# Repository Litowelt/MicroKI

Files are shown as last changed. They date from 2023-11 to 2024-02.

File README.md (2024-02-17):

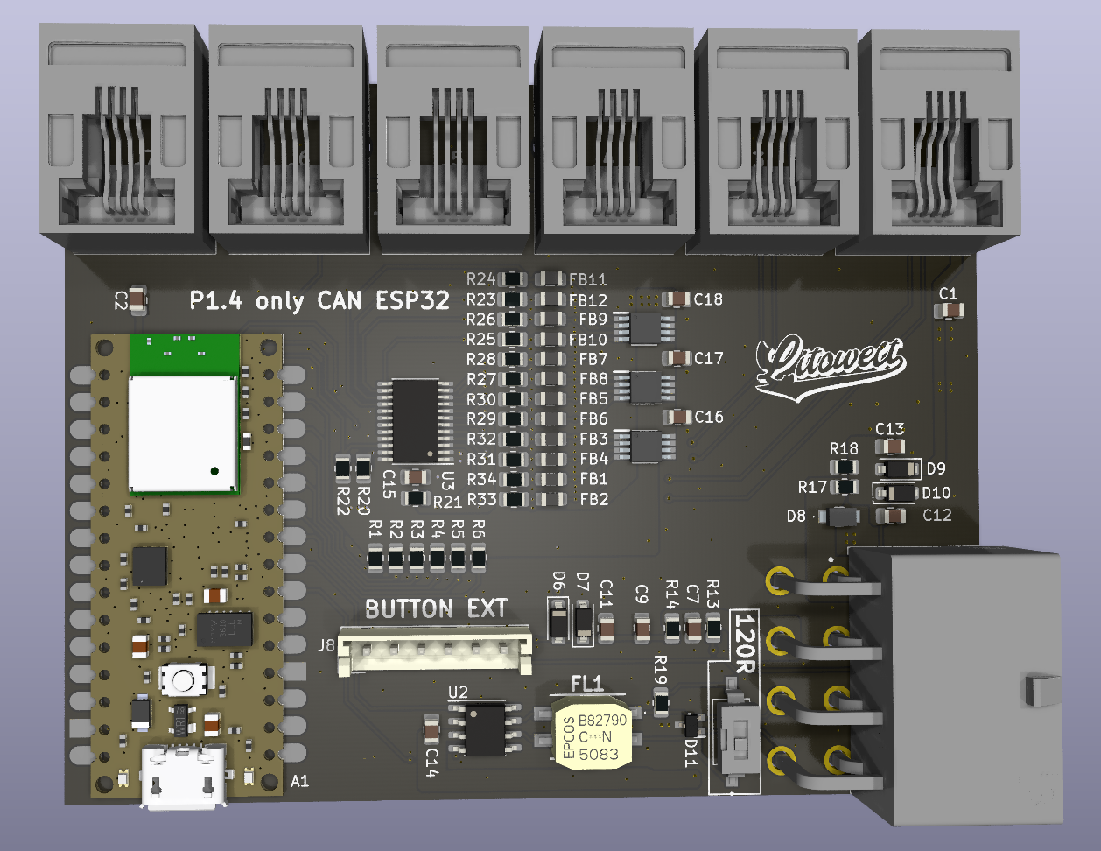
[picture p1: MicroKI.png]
HierSollteEigentlichEinFotoSein...


# MicroKI

Das "MicroKI" ist ein Projekt, das sich mit digitalen Zusatzanzeigen befasst. Das MicroKI ermöglicht den Anschluss von bis zu 6 Zusatzanzeigen (0.96" OLED LCDs) an ein System. Die Daten für diese Anzeigen können entweder über den CAN-Bus (1x) oder über externe Sensor-Eingänge bezogen werden. Es stehen verschiedene externe Sensor-Eingänge zur Verfügung, darunter Batterie Spannung und Öldruck. Jede der 6 Anzeigen kann separat angesteuert werden und die Daten können über Tasten auf der Platine oder externe Tasten umgeschaltet werden.

# Anschluss Übersicht
Digitale Zusatzanzeigen (0.96" OLED LCDs):

- Bis zu 6 dieser Displays können an das MicroKI angeschlossen werden.

Datenquelle:

- Die Daten können über den CAN-Bus (1x) oder über externe Sensor-Eingänge bezogen werden.
  
Externe Sensor-Eingänge:

- 1x Batterie Spannung
- 1x Öldruck Sensor (VDO)
  
Steuerung und Umschaltung:

- Alle 6 Anzeigen können separat angesteuert werden.
- Die Umschaltung zwischen den Anzeigen und die Steuerung erfolgen entweder über die Buttons auf der Platine oder über externe Buttons.

# Unterstütze Fahrzeuge und Nachrichten

- VW T5.1
  - Öl Temperatur (wenn der Sensor verbaut ist) - ✓
  - Kühlwasser Temperatur - ✓
  - Ladeluft Temperatur - ✓
  - Außentemperatur (wenn der Sensor verbaut ist) - ✓
  - Ladedruck - ✓
 
- Universal (Analoge Eingänge)
  - Öl Temperatur - X
  - Kühlwasser Temperatur - X
  - Außentemperatur - X
  - Öldruck - X
  - Ladedruck - X
 
# ToDo
- Code fertig schreiben. - in Arbeit
- Prototypen V2 bauen (Bauteile und Platinen sind bestellt).
- CAN Nachrichten für T5.2 heraus finden. - Müssen nur noch final getestet werden
- CAN Support für Haltech ECU hinzufügen - in Arbeit
- CAN Support für Ecumaster EMU ECU hinzufügen - in Arbeit
- CAN Support für Maxx ECU hinzufügen - in Arbeit

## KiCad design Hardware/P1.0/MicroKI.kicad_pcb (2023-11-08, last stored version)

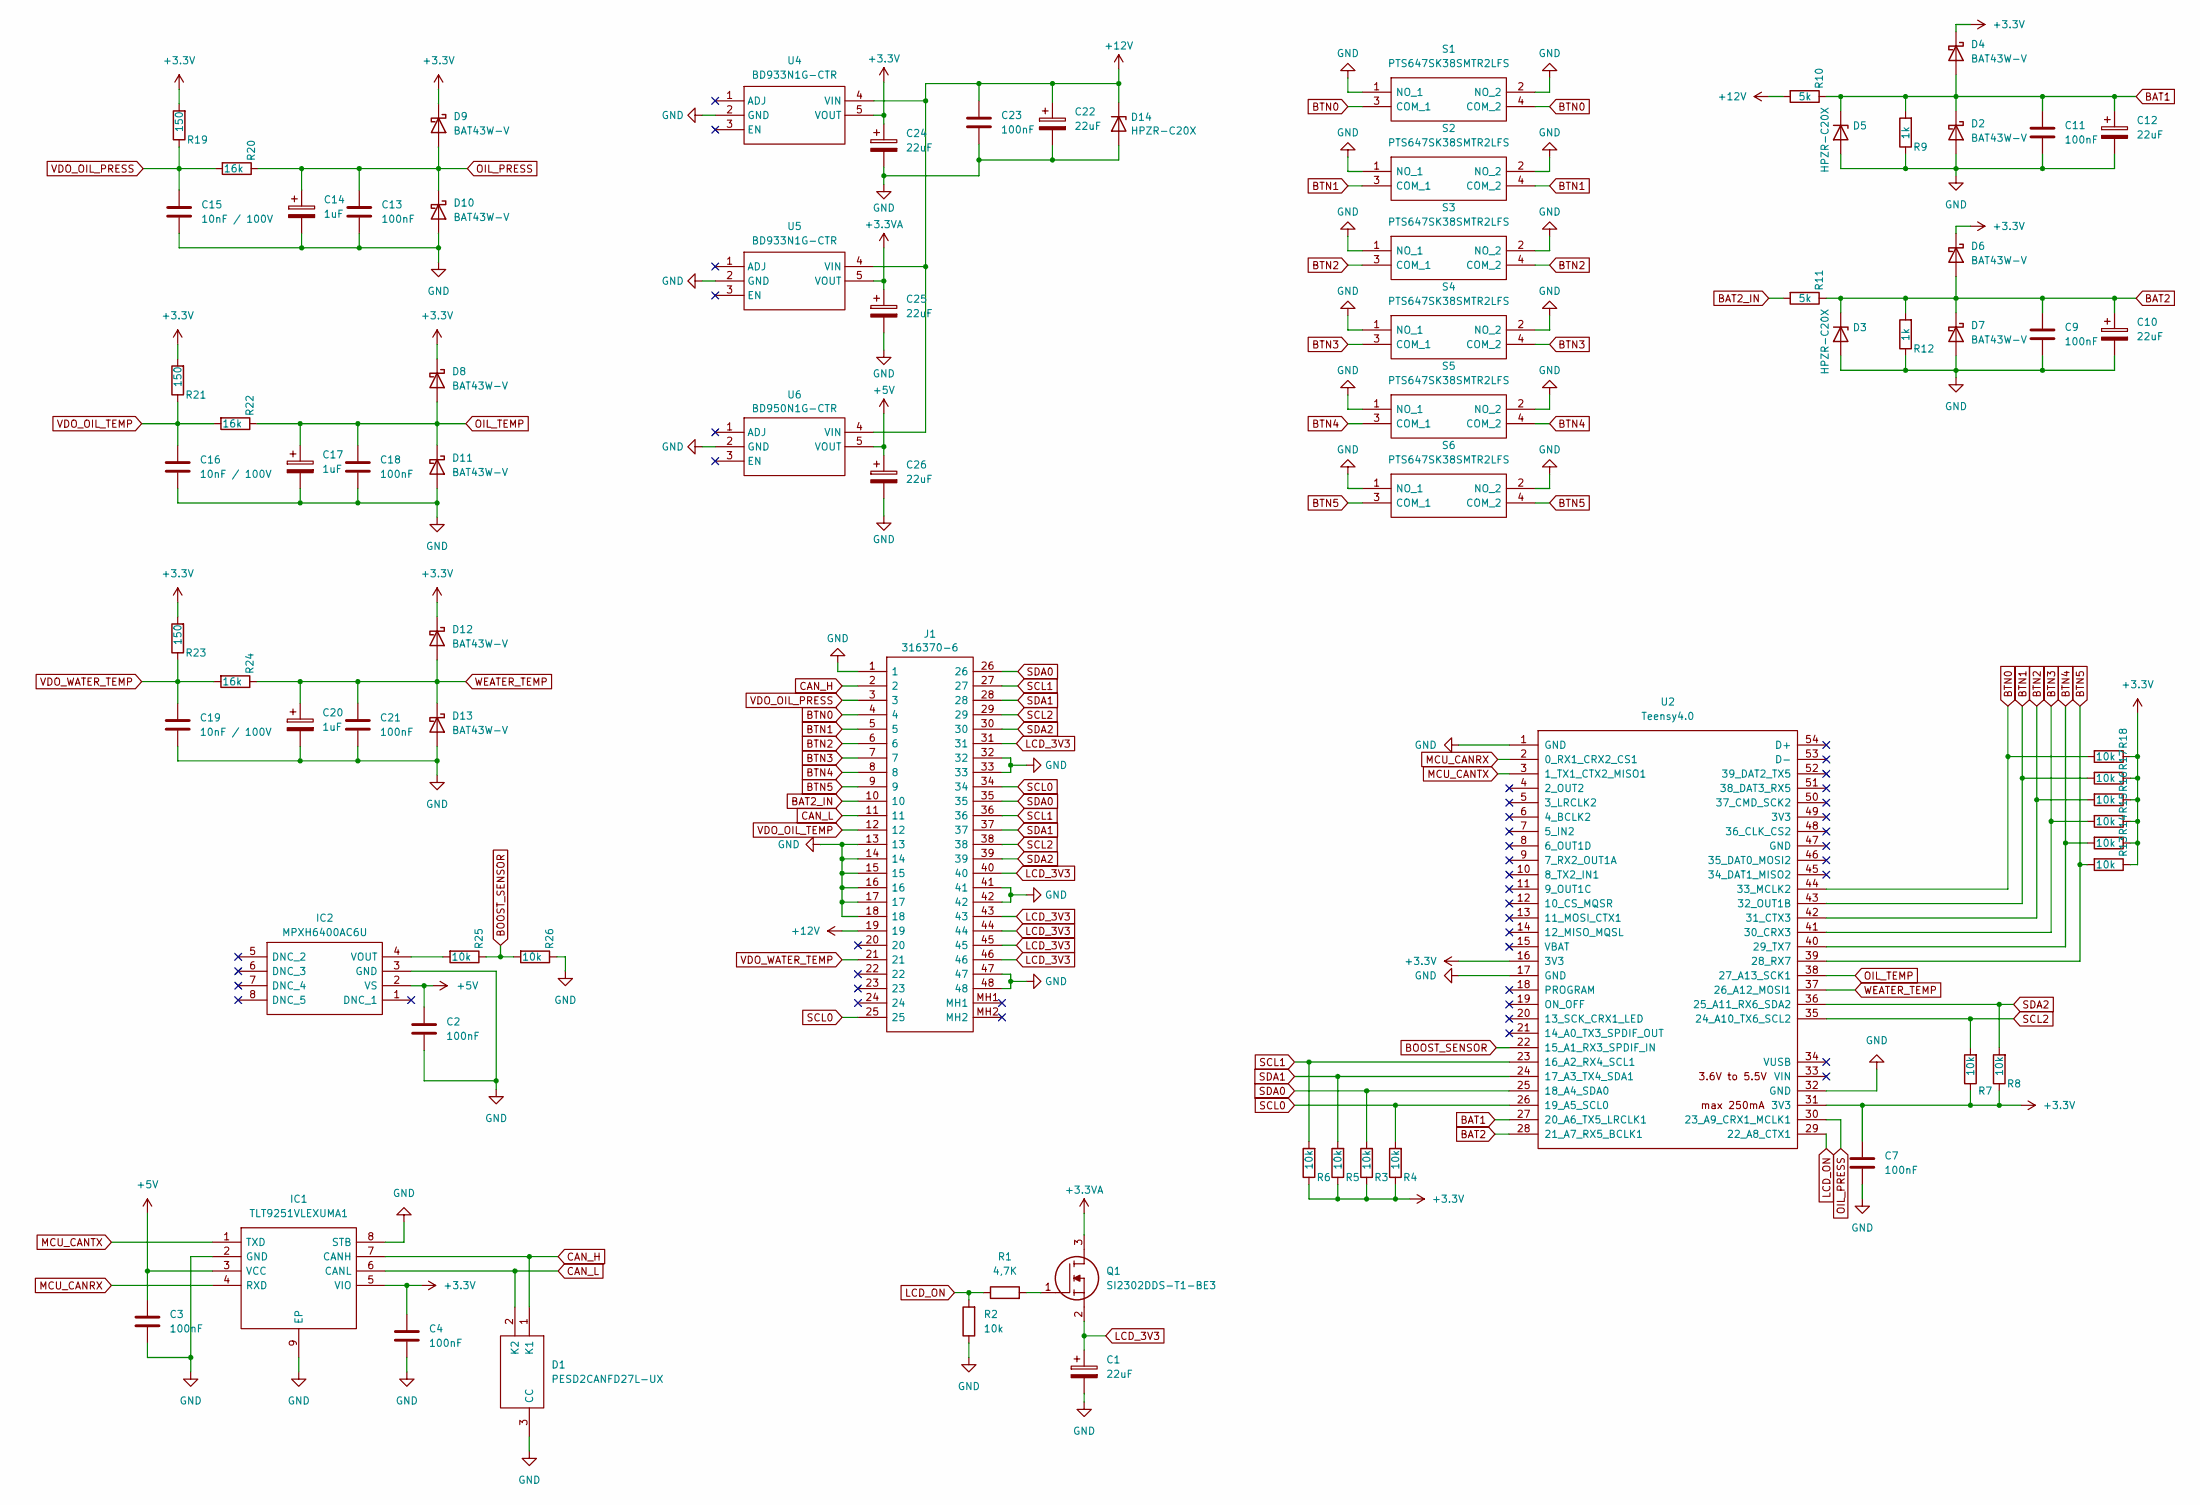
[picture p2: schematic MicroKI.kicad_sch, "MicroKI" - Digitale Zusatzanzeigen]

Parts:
C1, C10, C12, C22, C24, C25, C26: 22uF; CP_Elec_5x5.4; Manufacturer_Part_Number 865080442004; Mouser Part Number 710-865080442004
C2, C3, C4, C7, C9, C11, C13, C18, C21, C23: 100nF; C_0805_2012Metric_Pad1.18x1.45mm_HandSolder; Manufacturer_Part_Number C0805C104M5RAC7025; Mouser Part Number 80-C0805C104M5RACTM
C14, C17, C20: 1uF; CP_Elec_4x5.7; Manufacturer_Part_Number 865060640001; Mouser Part Number 710-865060640001
C15, C16, C19: 10nF / 100V; C_0603_1608Metric_Pad1.08x0.95mm_HandSolder; Manufacturer_Part_Number GCM188R72A103KA37J; Mouser Part Number 81-GCM188R72A103KA7J
D1: PESD2CANFD27L-UX; SOT65P210X110-3N; Mouser Part Number 771-PESD2CANFD27L-UX
D2, D4, D6, D7, D8, D9, D10, D11, D12, D13: BAT43W-V; D_SOD-123; Manufacturer_Part_Number BAT43W-G3-08; Mouser Part Number 78-BAT43W-G3-08
D3, D5, D14: HPZR-C20X; HPZRC20X; Manufacturer_Part_Number HPZR-C20X; Mouser Part Number 771-HPZR-C20X
IC1: TLT9251VLEXUMA1; SON65P300X300X110-9N; Manufacturer_Part_Number TLT9251VLEXUMA1; Mouser Part Number 726-TLT9251VLEXUMA1
IC2: MPXH6400AC6U; MPXH6115AC6U; Mouser Part Number 841-MPXH6400AC6U
J1: 316370-6; 3163706; Mouser Part Number 571-316370-6
Q1: SI2302DDS-T1-BE3; SOT95P237X112-3N; Mouser Part Number 78-SI2302DDS-T1-BE3
R1: 4,7K; R_0805_2012Metric_Pad1.20x1.40mm_HandSolder; Manufacturer_Part_Number RK73B2ATTD472J; Mouser Part Number 660-RK73B2ATTD472J
R2, R3, R4, R5, R6, R7, R8, R13, R14, R15, R16, R17, R18, R25, R26: 10k; R_0805_2012Metric_Pad1.20x1.40mm_HandSolder; Manufacturer_Part_Number RC0805FR-1010KL; Mouser Part Number 603-RC0805FR-1010KL
R9, R12: 1k; R_0805_2012Metric_Pad1.20x1.40mm_HandSolder; Manufacturer_Part_Number ERJ-P06D1001V; Mouser Part Number 667-ERJ-P06D1001V
R10, R11: 5k; R_0805_2012Metric_Pad1.20x1.40mm_HandSolder; Manufacturer_Part_Number CRCW08055K00FKTA; Mouser Part Number 71-CRCW0805-5K
R19, R21, R23: 150; R_0805_2012Metric_Pad1.20x1.40mm_HandSolder; Manufacturer_Part_Number ERJ-P06D1500V; Mouser Part Number 667-ERJ-P06D1500V
R20, R22, R24: 16k; R_0805_2012Metric_Pad1.20x1.40mm_HandSolder; Manufacturer_Part_Number RC0805FR-0716KL; Mouser Part Number 603-RC0805FR-0716KL
S1, S2, S3, S4, S5, S6: PTS647SK38SMTR2LFS; Mouser Part Number 611-PTS647SK38SMTR2L
U2: Teensy4.0; Teensy40_SMT
U4, U5: BD933N1G-CTR; BD9xxN1WG-CTR; Manufacturer_Part_Number BD933N1G-CTR; Mouser Part Number 755-BD933N1G-CTR
U6: BD950N1G-CTR; BD9xxN1WG-CTR; Manufacturer_Part_Number BD950N1G-CTR; Mouser Part Number 755-BD950N1G-CTR

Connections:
+3.3V: C4.1, C7.1, C24.1, D4.1 (K), D6.1 (K), D8.1 (K), D9.1 (K), D12.1 (K), IC1.5 (VIO), R3.1, R4.1, R5.1, R6.1, R7.1, R8.1, R13.1, R14.1, R15.1, R16.1, R17.1, R18.1, R19.2, R21.2, R23.2, U2.16 (3V3), U2.31 (3V3), U4.5 (VOUT)
+3.3VA: C25.1, Q1.3, U5.5 (VOUT)
+5V: C2.1, C3.1, C26.1, IC1.3 (VCC), IC2.2 (VS), U6.5 (VOUT)
+12V: C22.1, C23.1, D14.1 (K), J1.19, R10.2, U4.4 (VIN), U5.4 (VIN), U6.4 (VIN)
BAT1: C11.1, C12.1, D2.1 (K), D4.2 (A), D5.1 (K), R9.2, R10.1, U2.27 (20_A6_TX5_LRCLK1)
BAT2: C9.1, C10.1, D3.1 (K), D6.2 (A), D7.1 (K), R11.1, R12.2, U2.28 (21_A7_RX5_BCLK1)
BAT2_IN: J1.10, R11.2
BOOST_SENSOR: R25.1, R26.2, U2.22 (15_A1_RX3_SPDIF_IN)
BTN0: J1.4, R18.2, S1.3 (COM_1), S1.4 (COM_2), U2.44 (33_MCLK2)
BTN1: J1.5, R17.2, S2.3 (COM_1), S2.4 (COM_2), U2.43 (32_OUT1B)
BTN2: J1.6, R16.2, S3.3 (COM_1), S3.4 (COM_2), U2.42 (31_CTX3)
BTN3: J1.7, R15.2, S4.3 (COM_1), S4.4 (COM_2), U2.41 (30_CRX3)
BTN4: J1.8, R14.2, S5.3 (COM_1), S5.4 (COM_2), U2.40 (29_TX7)
BTN5: J1.9, R13.2, S6.3 (COM_1), S6.4 (COM_2), U2.39 (28_RX7)
CAN_H: D1.1 (K1), IC1.7 (CANH), J1.2
CAN_L: D1.2 (K2), IC1.6 (CANL), J1.11
GND: C1.2, C2.2, C3.2, C4.2, C7.2, C9.2, C10.2, C11.2, C12.2, C13.2, C14.2, C15.2, C16.2, C17.2, C18.2, C19.2, C20.2, C21.2, C22.2, C23.2, C24.2, C25.2, C26.2, D1.3 (CC), D2.2 (A), D3.2 (A), D5.2 (A), D7.2 (A), D10.2 (A), D11.2 (A), D13.2 (A), D14.2 (A), IC1.2 (GND), IC1.8 (STB), IC1.9 (EP), IC2.3 (GND), J1.1, J1.13, J1.14, J1.15, J1.16, J1.17, J1.18, J1.32, J1.33, J1.41, J1.42, J1.47, J1.48, R2.1, R9.1, R12.1, R26.1, S1.1 (NO_1), S1.2 (NO_2), S2.1 (NO_1), S2.2 (NO_2), S3.1 (NO_1), S3.2 (NO_2), S4.1 (NO_1), S4.2 (NO_2), S5.1 (NO_1), S5.2 (NO_2), S6.1 (NO_1), S6.2 (NO_2), U2.1 (GND), U2.17 (GND), U2.32 (GND), U4.2 (GND), U5.2 (GND), U6.2 (GND)
LCD_3V3: C1.1, J1.31, J1.40, J1.43, J1.44, J1.45, J1.46, Q1.2
LCD_ON: R1.1, R2.2, U2.29 (22_A8_CTX1)
MCU_CANRX: IC1.4 (RXD), U2.2 (0_RX1_CRX2_CS1)
MCU_CANTX: IC1.1 (TXD), U2.3 (1_TX1_CTX2_MISO1)
unnamed: IC2.4 (VOUT), R25.2
unnamed: Q1.1, R1.2
OIL_PRESS: C13.1, C14.1, D9.2 (A), D10.1 (K), R20.1, U2.30 (23_A9_CRX1_MCLK1)
OIL_TEMP: C17.1, C18.1, D8.2 (A), D11.1 (K), R22.1, U2.38 (27_A13_SCK1)
SCL0: J1.25, J1.34, R4.2, U2.26 (19_A5_SCL0)
SCL1: J1.27, J1.36, R6.2, U2.23 (16_A2_RX4_SCL1)
SCL2: J1.29, J1.38, R7.2, U2.35 (24_A10_TX6_SCL2)
SDA0: J1.26, J1.35, R3.2, U2.25 (18_A4_SDA0)
SDA1: J1.28, J1.37, R5.2, U2.24 (17_A3_TX4_SDA1)
SDA2: J1.30, J1.39, R8.2, U2.36 (25_A11_RX6_SDA2)
VDO_OIL_PRESS: C15.1, J1.3, R19.1, R20.2
VDO_OIL_TEMP: C16.1, J1.12, R21.1, R22.2
VDO_WATER_TEMP: C19.1, J1.21, R23.1, R24.2
WEATER_TEMP: C20.1, C21.1, D12.2 (A), D13.1 (K), R24.1, U2.37 (26_A12_MOSI1)

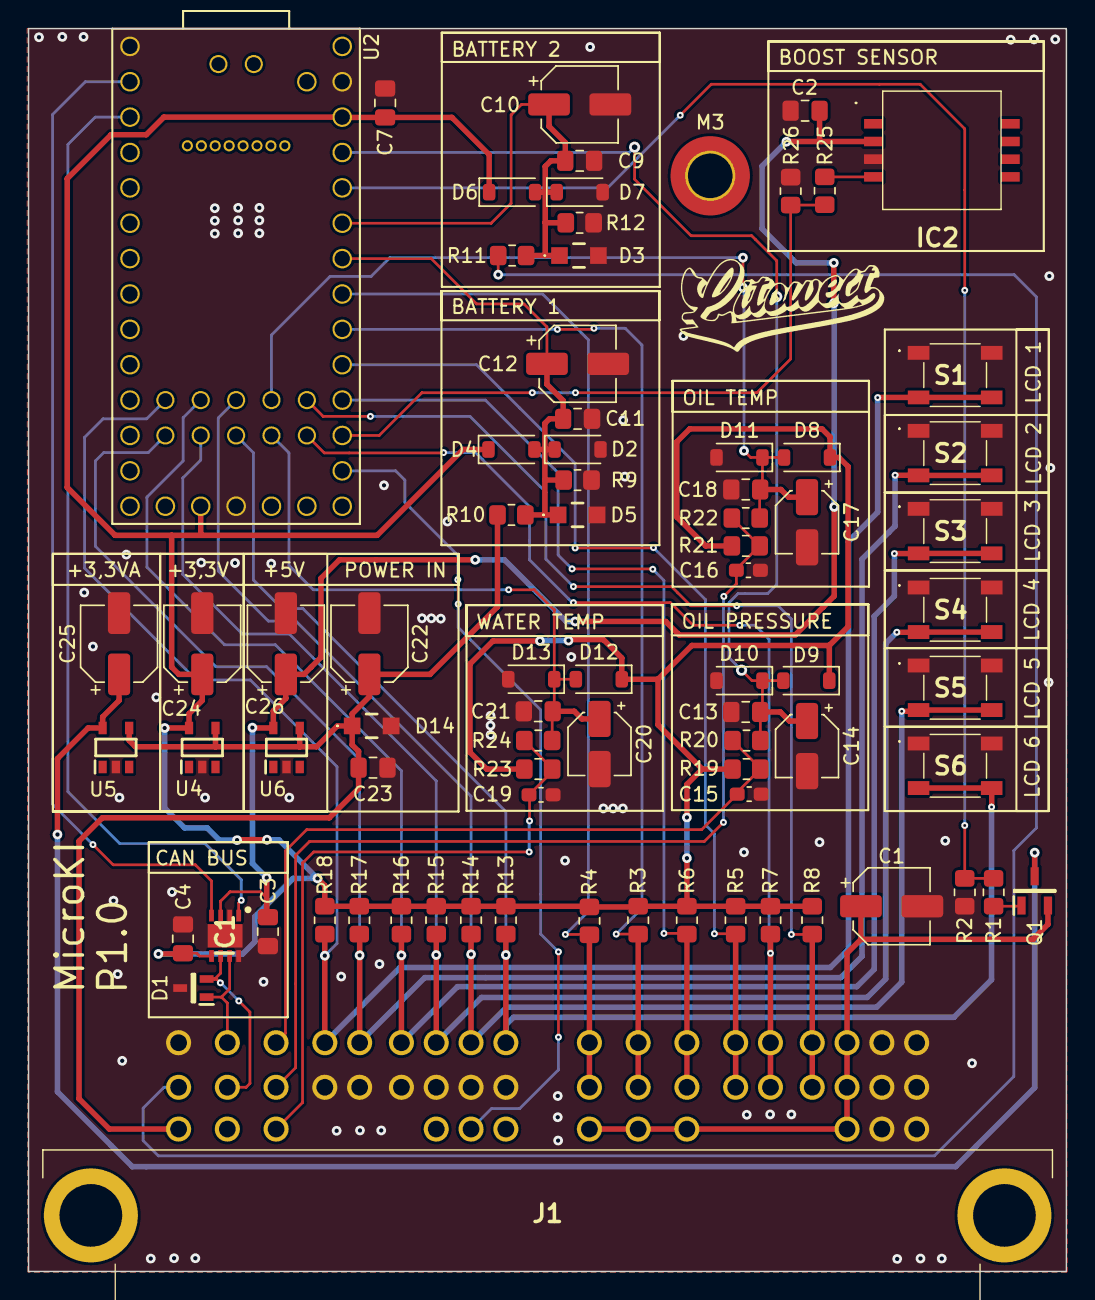
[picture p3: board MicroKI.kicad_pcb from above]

Board: 2 copper layers, 74.5 x 89.3 mm, 78 parts (0 on the bottom side), 35 nets.

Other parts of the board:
M3: MountingHole_3.2mm_M3_ISO7380_Pad_TopBottom

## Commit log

2023-11-07 Create Prototype
2023-11-08 Uploaded Prototype V. P1.0
    This is just a prototype! I make no guarantees that it works. Use at your own risk!
    [MicroKI.kicad_pcb, MicroKI.kicad_sch]
2023-11-08 Added gerber files
    [MicroKI-B_Cu.gbl, MicroKI-B_Mask.gbs, MicroKI-B_Paste.gbp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]
2023-12-09 Add files via upload
    Prototyp Version 1.1 - NICHT GETESTET
    [MicroKI.kicad_sch, MicroKI2.csv, analog_inputs.kicad_sch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]
2024-02-17 Create P1.4 only CAN ESP32
